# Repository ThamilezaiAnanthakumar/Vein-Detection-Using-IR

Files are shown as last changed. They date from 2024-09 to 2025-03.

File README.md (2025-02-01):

# Vein Detection System  

Enhancing vein detection for healthcare professionals with an efficient and accessible device.  

---  

## 📂 Repository Overview  

This repository contains all the resources and files related to our vein detection system project.  

### **Included Files**  
- **Code Files**: Arduino code for controlling the TFT display.  
- **PCB Files**: Schematic and PCB layout designs detailing hardware connections.  
- **Enclosure Files**: 3D models and designs for the physical enclosure.  
- **Final Report**: Comprehensive documentation including:  
  - Project objectives and design diagrams.  
  - Simulation and testing methodologies.  
  - Results and resource optimization strategies.  
  - Team contributions.  
  - Practical operation instructions.  

---  

## 🛠️ How It Works  

- The system uses an **ESP32-CAM module** to capture real-time images.  
- Images are streamed wirelessly to a browser via Wi-Fi.  
- A **circular LED array** enhances visibility for detecting veins.  
- The built-in **ESP32 camera web server** enables live streaming.  

---

## 💡 Why We Chose the ESP32-CAM  

For this project, we opted for the **ESP32-CAM module** due to second-semester restrictions requiring:  
- Custom PCB design.  
- Soldering for the hardware setup.  

This approach fulfilled the requirements but resulted in lower image quality, a limitation we plan to address in future iterations.  

---

## 🚀 Future Improvements  

To improve the system, we propose:  
1. **Using a Raspberry Pi and NoIR Camera** for better image quality.  
2. **Applying Edge Detection Techniques** to clearly outline veins.  

These enhancements would significantly improve the clarity and usability of the system.  

---

## 🔑 Key Components  

- **ESP32-CAM Module**: Captures and streams real-time images.  
- **Circular LED Array**: Improves vein visibility.  
- **ESP32 Camera Web Server**: Provides a wireless interface for live streaming.  

---

## 🎯 Project Purpose  

This project is designed to assist healthcare professionals by:  
- Making vein detection more efficient.  
- Enhancing the accuracy of procedures like blood draws and cannulation.  

---
👥 Contributors
- [Thamilezai Ananthakumar](https://github.com/ThamilezaiAnanthakumar)- Circuit Design , Documentation,Software Development,Code Integration & Testing
- [Dayananthan](https://github.com/Dayananthan2021)- Circuit Design & PCB Design & Soldering & Testing
- [Imesh Abeysinghe](https://github.com/1234imesh)- Circuit Design & Enclosure Design

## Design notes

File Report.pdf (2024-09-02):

# Vein Detection

Enhancing Precision, Reducing Discomfort in Healthcare

## Project Report

220009H Abeysinghe G. A. I. N. M

220029T Ananthakumar.T

220096T Dayananthan.T

Department of Electronics and Telecommunication Engineering

University of Moratuwa, Sri Lanka

August 22, 2024

## Content

Device Design Report

ABSTRACT

Vein detection technology makes it easier to find veins, which is particularly important for procedures like blood draws and IV insertions. For small children, people with darker skin, and the elderly, locating veins can be challenging due to varying skin types and vein visibility. This system uses infrared light and advanced image processing to clearly display veins on a screen, helping healthcare providers quickly and accurately find veins. This technology not only improves the precision of medical procedures but also reduces discomfort and stress for patients, making it a valuable tool in providing effective and compassionate healthcare.

Device Design Report

### 1. Introduction

In the healthcare sector, accurate and efficient vein detection is crucial. . Traditional vein detection systems can be expensive and often require specialized equipment that is not always accessible in every healthcare setting. Our project addresses these challenges by developing a cost-effective, smart vein detection system that provides a clear and accurate visualization of veins. This device is designed to be accessible via a web-based interface. By offering a budget-friendly solution that combines with ease of use, we aim to improve the efficiency and accuracy of medical procedures while making vein detection more accessible to a broader range of healthcare facilities.

### 2. Background Research

The background research for developing the vein detection system covered several key areas, including hardware components, imaging techniques, and programming languages.The following sections provide an overview of the components and technologies that are integral to the project, ensuring the system is both functional and user-friendly.

ESP WROOM S3 U1 Microcontroller

The ESP WROOM S3 U1 microcontroller is strategically chosen for the vein detection project due to its advanced processing capabilities and substantial memory resources, making it particularly well-suited for image processing tasks. Powered by the ESP32-S3 SoC, this microcontroller features a dual-core Xtensa LX7 processor operating at 240MHz, delivering the high-performance computational power necessary for real-time image analysis. With support for up to 16 MB of PSRAM, the ESP WROOM S3 U1 offers significant memory capacity, enabling efficient handling of complex image data critical for

Device Design Report

Accurate vein detection. Additionally, the integrated Wi-Fi and Bluetooth functionalities facilitate seamless communication of processed data, further solidifying the ESP WROOM S3 U1 as an optimal choice for applications requiring precision and reliability in image-based projects like vein detection compared to other ESP chips

ESP CAM

For the vein detection project, the ESP32-CAM module was selected due to its flexibility and adaptability, particularly in scenarios where a NoIR (No Infrared) camera is essential. While Raspberry Pi cameras with NoIR capability are available, they are not compatible with the ESP32 microcontroller, which is a core component of our project. To address this limitation, we opted to use the ESP32-CAM module and modify it by removing the infrared (IR) filter. This modification allows the camera to capture the infrared wavelengths necessary for effective vein detection.

TFT 1.8’ LCD display

The TFT 1.8” LCD display was chosen for the vein detection project due to its efficient SPI communication, which offers fast data transfer with minimal latency, making it ideal for live streaming applications. The compact size of the display contributes significantly to reducing the overall footprint of the product, aligning with the project’s goal of creating a portable and space-efficient device. Additionally, the cost-effectiveness of the TFT 1.8” LCD display makes it a practical choice, ensuring that the project remains budget-friendly without compromising on performance or quality.

LED Array and IR LED

The design incorporates a circular LED array with IR LEDs strategically placed around the camera, which is positioned at the center. This configuration ensures optimal capture of the reflected infrared light, enhancing the efficacy of image acquisition for vein detection. The IR LEDs operate at a wavelength of 850 nm, which is highly suitable for vein detection due to its ability to penetrate the skin and highlight veins effectively. To ensure the safety and longevity of the LEDs, suitable resistors have been selected to regulate the current, preventing overheating and ensuring consistent performance.

Lithium battery and Charging Module USB Booster

We required a 5V to 8.5V battery to power our PCB, but only 3.7V batteries were available. To meet the voltage requirement, we combined two 3.7V lithium batteries in series. Additionally, since we're using lithium batteries, we included a USB port for recharging the PCB to ensure convenient and reliable power management.

Device Design Report

### 3. Project Description

### 3.1 Circuit Design

In order to develop the vein detection system, we utilized several key schematics to achieve the desired functionality. The primary components used in the circuit include the ESP WROOM S3 U1 microcontroller, a circular IR LED array, potentiometers, resistors, and a camera module. The ESP WROOM S3 U1 managing communication tasks with display. The circular IR LED array, designed with carefully selected resistors and a potentiometer, ensures optimal illumination for vein visualization by providing controlled infrared light around the camera module. The following sections provide an overview of each circuit used in this design,

IR Led Array

The IR LED array schematic was custom-designed based on our specific requirements for the vein detection system. The design process involved manually calculating the resistor values to ensure the safety and longevity of the IR LEDs, preventing overheating and ensuring consistent performance. Additionally, the distance between each LED was carefully calculated to optimize the coverage and intensity of the infrared light, enhancing the efficiency of image capture. By strategically positioning the LEDs in a circular array around the camera, the design maximizes the reflection of infrared light, which is crucial for accurate vein visualization. This custom schematic effectively integrates the IR LED array into the overall system, ensuring high performance and reliability.

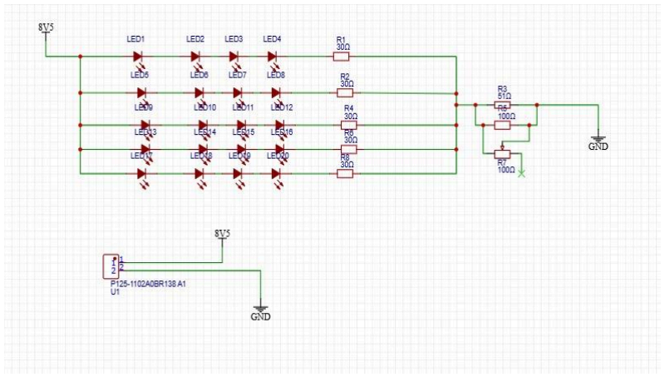
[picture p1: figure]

Device Design Report

ESP WROOM S3 U1

The circuit design began by incorporating the ESP WROOM S3 U1, a powerful and versatile Wi-Fi and Bluetooth-enabled microcontroller, into the system. To ensure stable and efficient performance, we used the ESP WROOM S3 U1 reference circuit provided by Espressif's official documentation as the foundation. Necessary modifications were made to tailor the reference design to the specific needs of our vein detection project, optimizing the circuit for image processing and real-time data communication while maintaining reliability and efficiency.

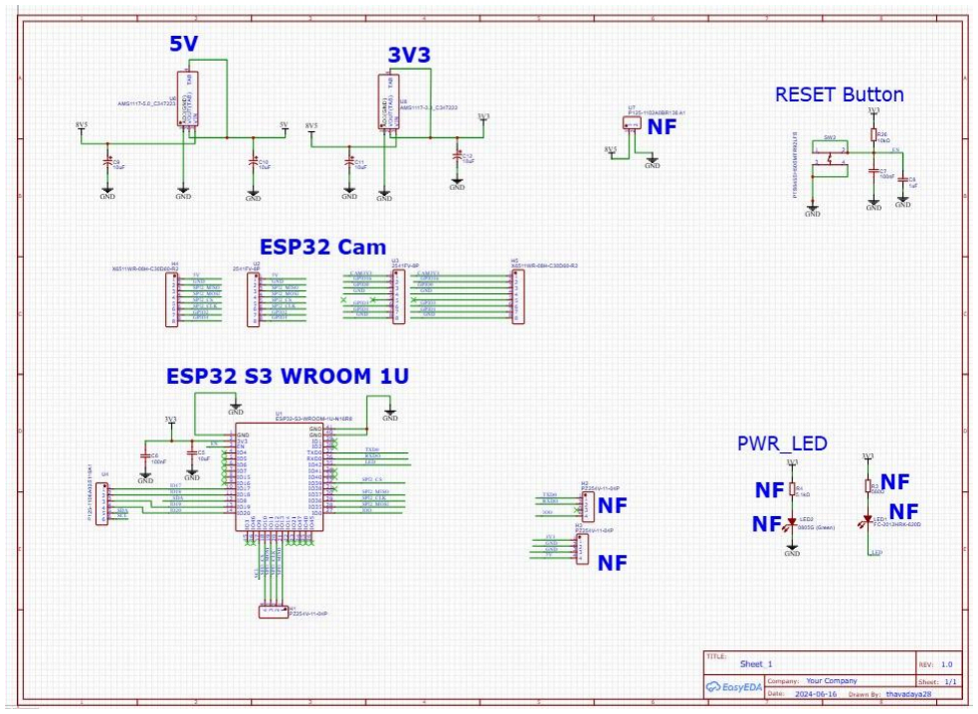
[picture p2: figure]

Device Design Report

### 3.2 PCB Design

The Vein Detection circuit has been designed using Altium Designer, enabling industry-standard PCB (Printed Circuit Board) design. In this section, we will explain various aspects of our PCB layout, including the placement of components, trace width, and clearance for critical nets. We will also discuss specific design rules implemented to ensure that the Vein Detection system operates reliably and without faults.

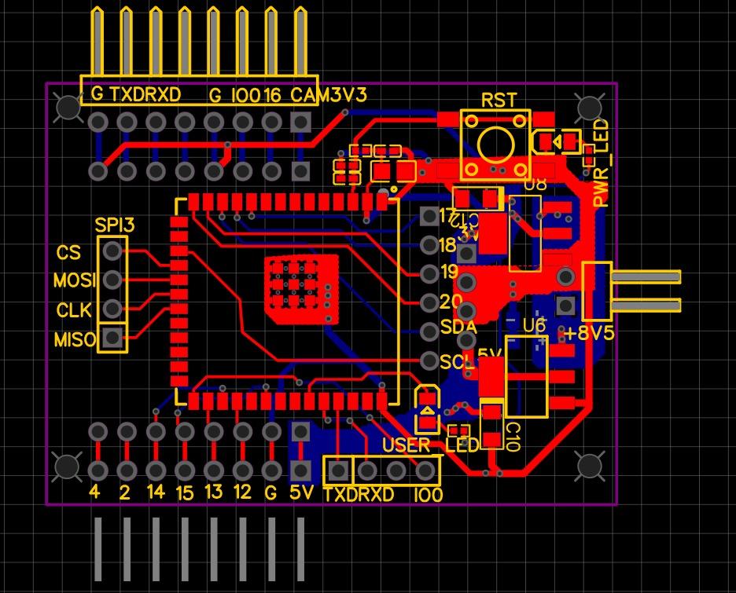
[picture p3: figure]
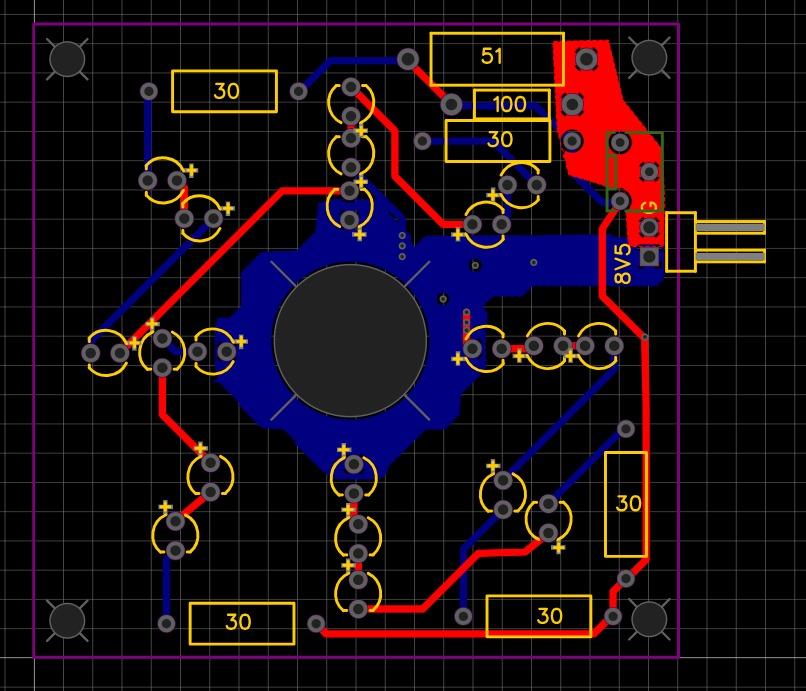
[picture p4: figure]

Device Design Report

Component Placement and 3D Models

In the PCB design process for the Vein Detection system, significant attention was given to the strategic placement of components to optimize performance, minimize noise, facilitate easy soldering, and reduce the overall size of the device. We utilized Altium’s manufacturer part search feature to obtain layouts and 3D models for most components, ensuring that selected parts are readily available in the market. Additionally, the SnapEDA website was used to obtain footprints for some components. The 3D models allowed us to conduct comprehensive mechanical checks, ensuring that there were no interferences with the enclosure or other components, thereby simplifying the assembly process.

Trace Width and Current Considerations

Trace Width and Current Considerations:
In the design of the Vein Detection system, careful attention was given to trace layout, particularly when designing the circular LED PCB where IR LEDs are positioned in close proximity. For the WROOM PCB, we prioritized proper trace sizing to ensure reliable operation and minimize any potential signal interference. Additionally, we incorporated reset buttons and header pins on both sides of the WROOM PCB to facilitate the mounting of the camera module. This strategic placement and trace design were crucial in optimizing the overall functionality and durability of the system.

Clearance and Safety Measures

Electrical safety was a primary concern in the PCB design for the Vein Detection system. To ensure proper operation and safety, we carefully managed clearances, particularly between high-voltage and low-voltage sections. For the camera module, which requires a stable 5V power supply to function correctly, we ensured that the power pins are appropriately designed to deliver the required voltage. This careful design consideration helps prevent operational issues with the camera and enhances the overall safety and reliability of the system.

Device Design Report

Issues with PCB design

Although we designed our PCB properly there is voltage drops less than 5 in each pin.

Future Implementations

In the future, we plan to enhance the PCB design for the Vein Detection system to prevent unwanted interactions, particularly between traces. We will increase the clearances between traces to improve safety and reliability.

Manufacturability and JLCPCB Guidelines:

Throughout the PCB design process, we remained aware of manufacturability requirements of the PCB. We referred to JLCPCB’s manufacturing guidelines to ensure our design complied with their fabrication capabilities and processes. JLCPCB’s .rul file was imported into the "Rules" section of our design software, and necessary changes were made. This proactive approach enabled us to minimize manufacturing errors, reduce production time, and optimize costs

Device Design Report

### 3.3 Enclosure Design

The enclosure design is optimized to ensure even stress distribution. Its curvature reduces the required material by minimizing wall thickness through the creation of hoop stress. Additionally, holes are strategically placed at the center to accommodate the camera.

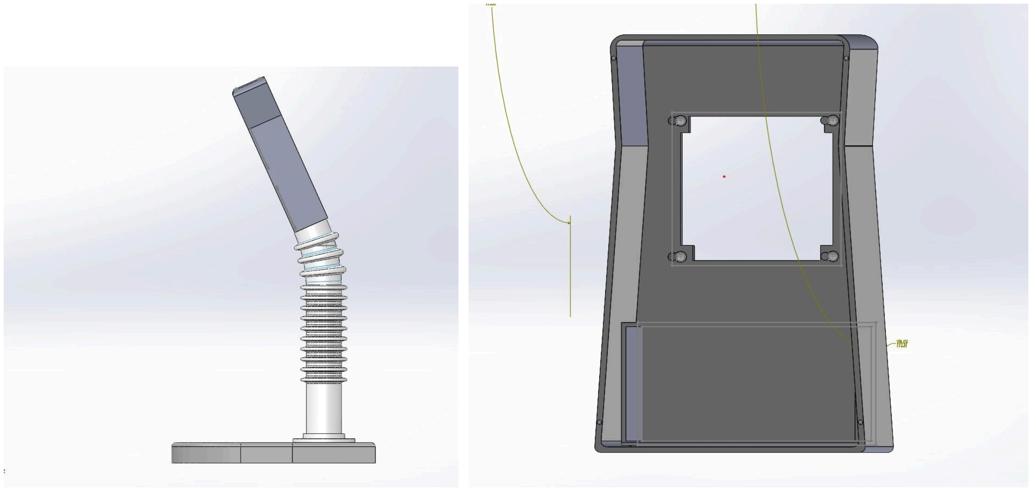
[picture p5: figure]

Technology used : 3D printing
Material used : PLA Bioplastic

The design is a very sleek, compatible and very minimal in size.

Issues with 3D printing :

The poles in the enclosure are breaking due to their small diameter, despite the use of high-quality materials. Additionally, alternative mounting solutions, such as standoffs or brackets, could be explored to reduce reliance on the poles for securing the PCB in the upcoming project. This approach will help to improve the overall durability and structural integrity of the design.

Device Design Report

### 3.4 Microcontroller Programming

We use Wi-Fi libraries and web server libraries to access the camera through a browser over Wi-Fi. For communication between the WROOM module and the display, we utilize SPI communication with the TFT_eSPI library. To simplify the project, we connect only one Wi-Fi network, ensuring a single IP address for both connection and disconnection. Specifically, the WROOM module handles SPI communication and displays the IP address, while the camera module runs the camera server.

Future Implementation

In the future, we plan to use a TFT touch LCD display with an alphanumeric keypad by class defined in Arduino to allow users to input Wi-Fi names and passwords directly on the display. This will enable the system to connect to various Wi-Fi networks, each with its own unique IP address. The WROOM and camera modules will then communicate to share Wi-Fi credentials and IP addresses, facilitating seamless connectivity and operation.

### 4. Non-technical issues

We faced unexpected costs because we had to buy components from China, adding $70 in shipping fees to our budget. Additionally, the TFT display was out of stock in Sri Lanka, which also required international shipping. As this is our first complete project, we weren’t prepared for these issues. For future projects, we will research suppliers more thoroughly, budget for unforeseen costs, seek local alternatives, plan logistics more carefully, and discuss cost-sharing arrangements with partners or clients to prevent similar problems.

### 5. Our progress and Limitations

### 1. Initial Idea: Live Stream Image Processing with OpenCV

- We aimed to capture live stream images using the ESP32-CAM and send them via Wi-Fi to a system running OpenCV for advanced image processing tasks, such as edge detection and noise removal.

Device Design Report

- The processed image was to be sent back to the WROOM chip, which, equipped with PSRAM, would then buffer and display the image on a TFT display through SPI communication.
- However, this approach encountered network termination errors with the OpenCV code, leading us to abandon this plan after unsuccessful implementation attempts.

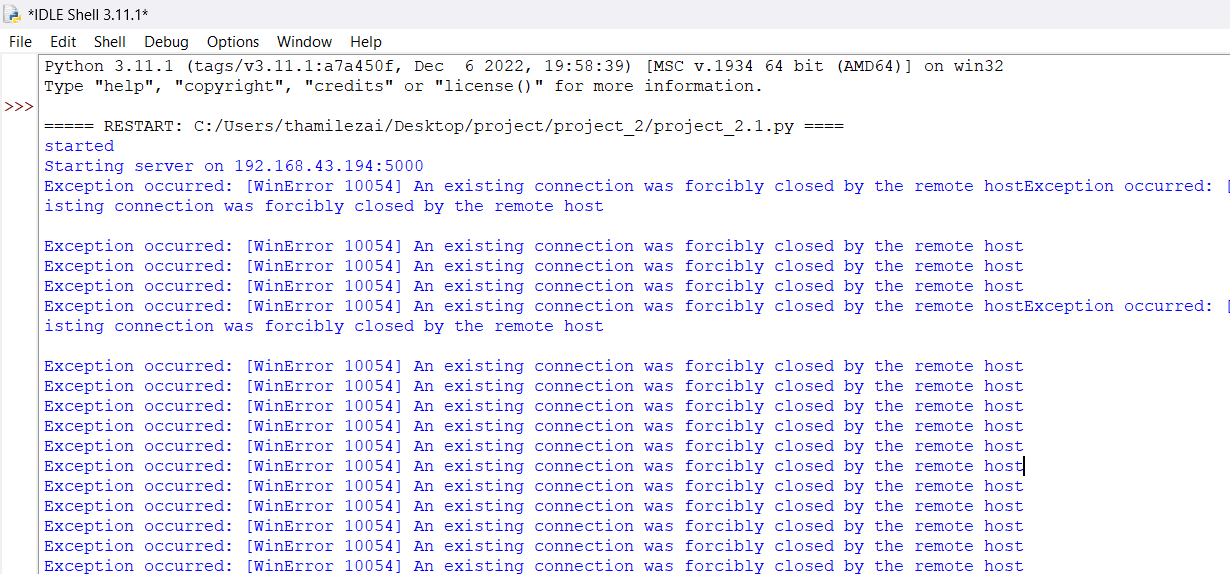
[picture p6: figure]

### 2. Alternative Approach: Simplified Image Processing with Arduino IDE

- We considered removing the OpenCV component and opted to capture images with the ESP32-CAM, apply basic noise removal using Arduino IDE, and then send the processed image to the TFT display via SPI communication.
- Unfortunately, the TFT display faced hardware limitations that prevented it from effectively displaying live-streamed images; it could handle text and graphics but struggled with image data, resulting in high noise and stuck frames.

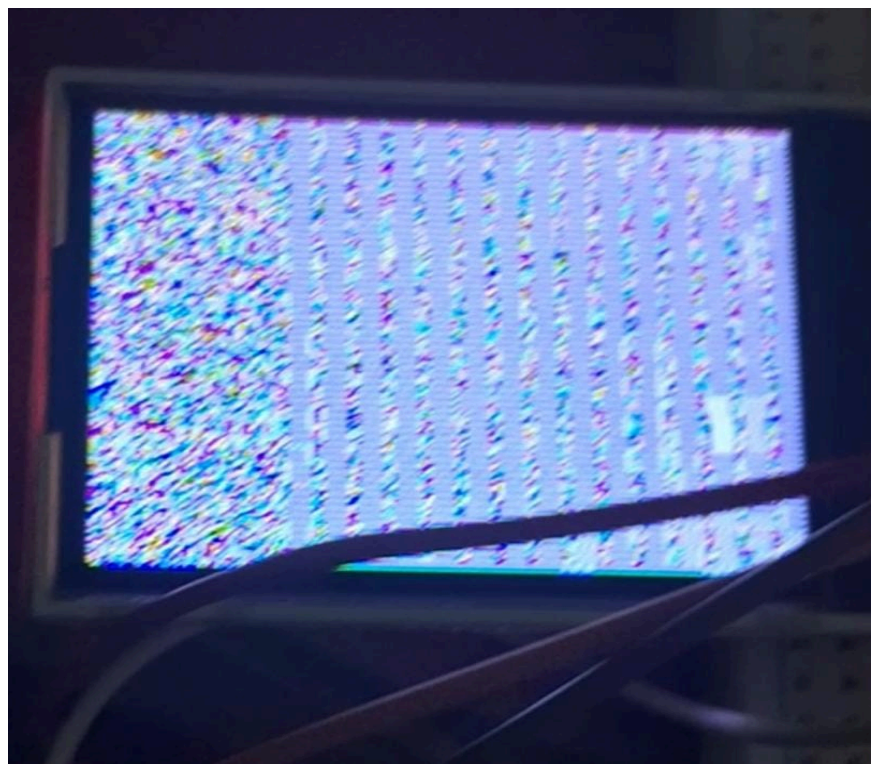
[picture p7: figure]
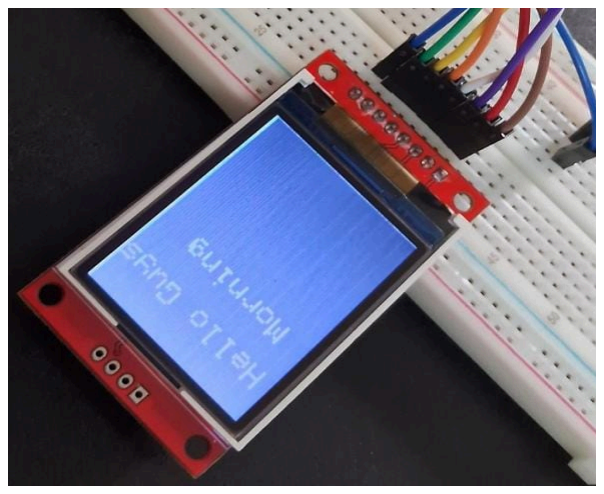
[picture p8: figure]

Device Design Report

### 3. Final Solution: Web Browser Display via Camera Server

- Given the issues with the TFT display, we shifted to displaying the captured image in a web browser using the camera server feature of the ESP32-CAM, utilizing web server and Wi-Fi libraries.
- By typing the IP address into a browser, users can view the image, and the WROOM chip displays this IP address on the TFT screen, which remains constant for a single Wi-Fi Connection.

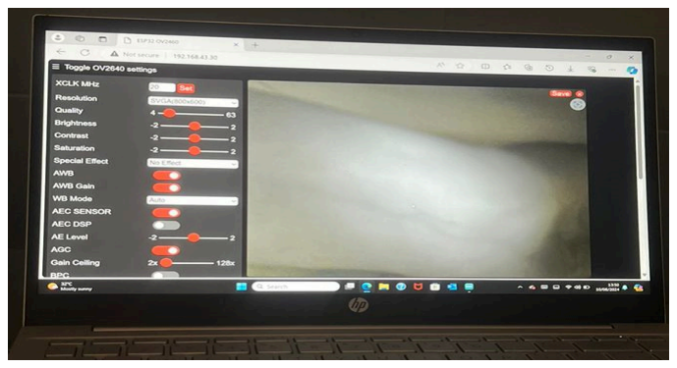
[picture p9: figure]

Camera Web Server Vein

### 4. Future Considerations: Mobile Accessibility

- After discussions with medical professionals, we learned that mobile accessibility is preferred for future projects. This feedback has led us to focus on solutions that are more mobile-friendly, aligning with user preferences and improving overall usability.
Each step reflects a thoughtful progression, responding to technical challenges and user feedback, leading to a more robust and user-centric solution.

Device Design Report

6.Task Allocation

Name | Task Allocation
Abeysinghe G. A. I. N. M | Product Enclosure Design with SolidWorks. Testing and Troubleshooting
Ananthakumar.T | Program Development. Testing and Troubleshooting
Dayananthan.T | PCB Designing using Altium and Product Soldering and Assembling the product. Testing and Troubleshooting

### 7. Conclusion and Future Work

Our project initially focused on developing a vein detection system, overcoming challenges related to image capture and processing. Despite technical and hardware limitations, we made significant progress in integrating components like the ESP32-CAM and TFT display. However, we faced issues with live image streaming and processing due to hardware constraints and network termination errors, which led us to pivot our approach multiple times.
Looking ahead, our future plan is to implement a 2.8" TFT touch display with an alphanumeric keypad, enabling users to input their network name and password directly on the device. This will allow for dynamic Wi-Fi connectivity, with communication between the WROOM and CAM modules to update and display variable IP addresses on the TFT screen. We aim to achieve this by defining classes for numeric and alphabetic input in Arduino IDE, enhancing the programming capabilities and functionality of the system.
Currently, we are facing some hardware limitations and time constraints, which have delayed the full implementation of these features. We plan to address these issues and complete the coding in the future, ultimately enabling the device to be more versatile and accessible via Wi-Fi for various users.

Device Design Report

### 7. Appendices

ESP- S3-WROOM-U1 : esp32-s3-wroom-1_wroom-1u_datasheet_en.pdf (espressif.com) (https://www.espressif.com/sites/default/files/documentation/esp32-s3-wroom-1_wroom-1u_datasheet_en.pdf)

ESP CAM : ESP32-CAM Camera Module Pinout, Datasheet, Features and Specs (components101.com) (https://components101.com/modules/esp32-cam-camera-module)

TFT 1.8’ display : 1.8" TFT Display Breakout and Shield Datasheet by Adafruit Industries
LLC | Digi-Key Electronics (digikey.com) (https://www.digikey.com/htmldatasheets/production/1942395/0/0/1/1-8-tft-display-breakout-and-shield.html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)

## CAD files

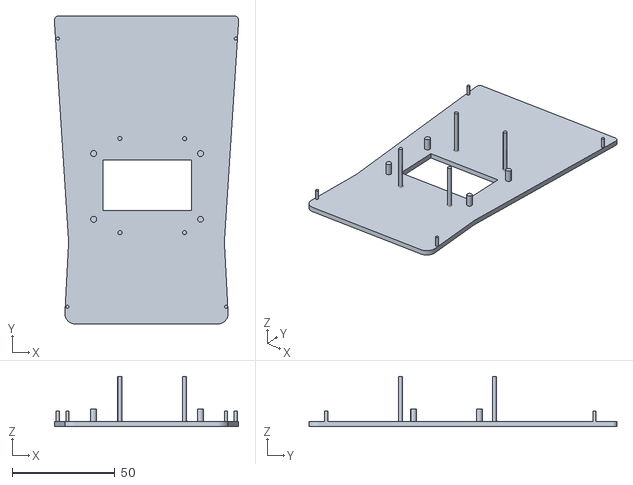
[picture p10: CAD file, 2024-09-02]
Enclosure/Main_Header.STL
89.7 x 149.9 x 24.5

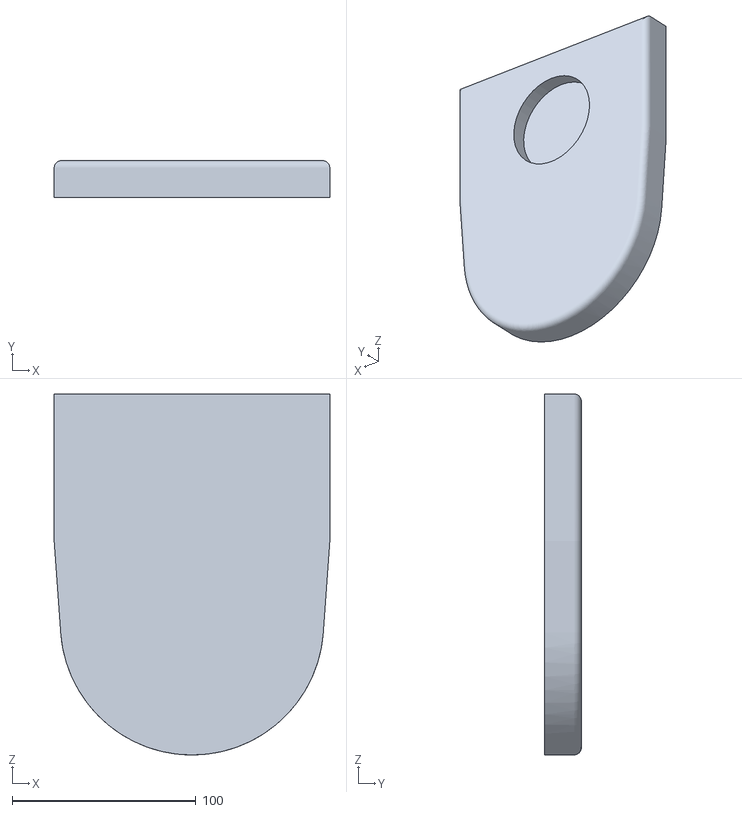
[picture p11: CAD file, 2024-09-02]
Enclosure/base.STL
150.0 x 20.0 x 196.4

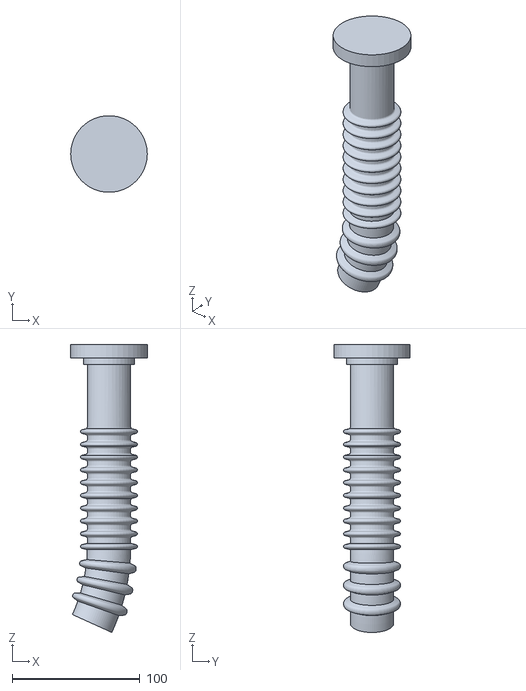
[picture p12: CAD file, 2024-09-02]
Enclosure/Bendable Neck.STL
60.0 x 59.8 x 225.5

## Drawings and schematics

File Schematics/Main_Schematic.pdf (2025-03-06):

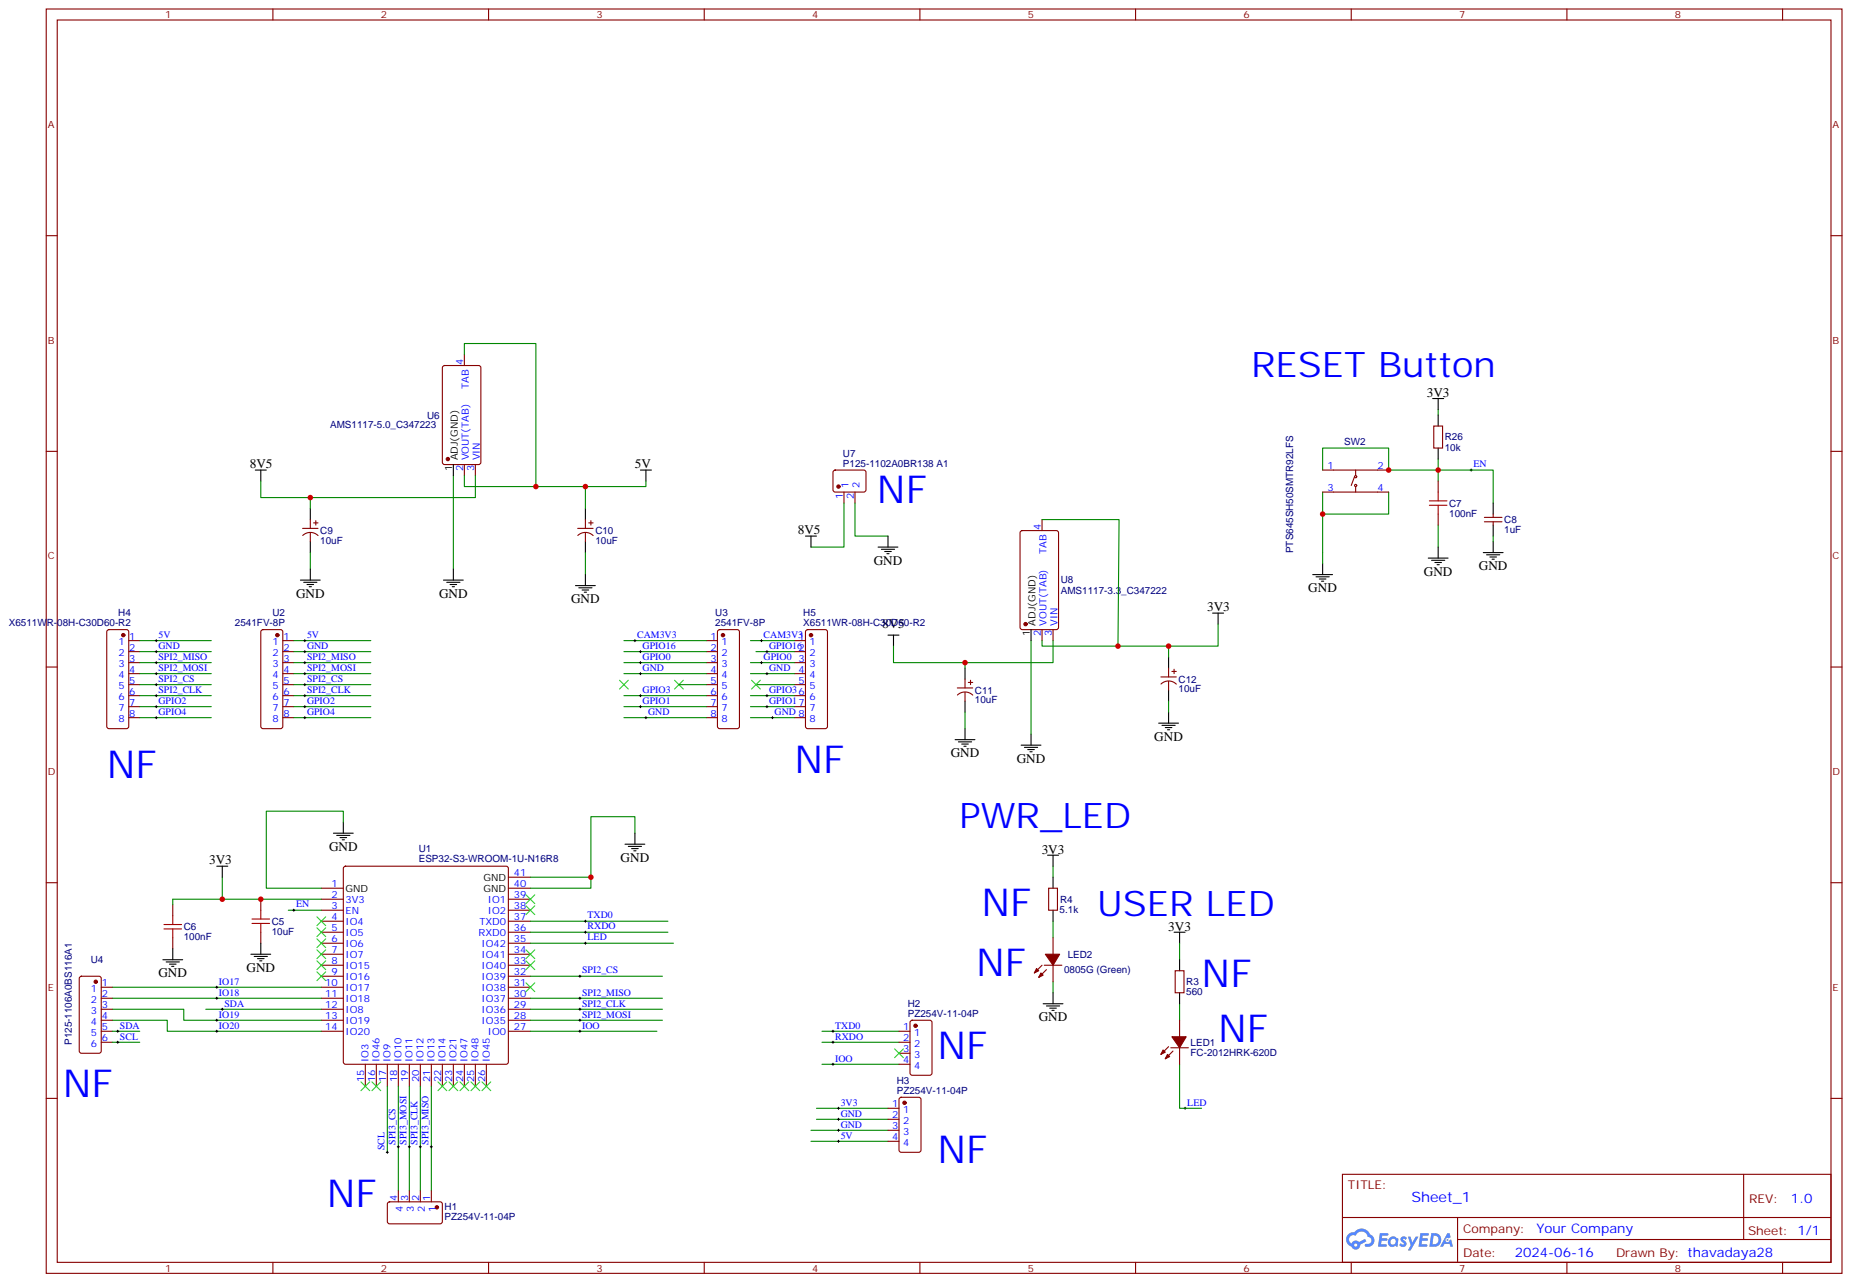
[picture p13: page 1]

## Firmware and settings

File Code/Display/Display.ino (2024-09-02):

#include <Adafruit_GFX.h>    // Core graphics library
#include <Adafruit_ST7735.h> // Hardware-specific library for ST7735
#include <SPI.h>

// Pin definitions for ESP32
#define TFT_CS      10    
#define TFT_RST     19   
#define TFT_DC      17   
#define TFT_MOSI    13  
#define TFT_SCLK    12   

// Create Adafruit ST7735 instance
Adafruit_ST7735 tft = Adafruit_ST7735(TFT_CS, TFT_DC, TFT_MOSI, TFT_SCLK, TFT_RST);

void setup(void) {
  Serial.begin(115200);

  // Initialize the display
  tft.initR(INITR_BLACKTAB);  // Init ST7735S chip, black tab

  // Set the background color to black
  tft.fillScreen(ST77XX_BLACK);

  // Display "Initializing....."
  tft.setTextColor(ST77XX_WHITE);
  tft.setTextSize(1);
  tft.setCursor(10, 50);
  tft.println("Initializing.....");
  
  delay(5000);

  // Clear the screen and display IP information
  tft.fillScreen(ST77XX_BLACK);
  tft.setTextColor(ST77XX_WHITE);
  tft.setTextSize(1);

  // Set cursor for each line
  tft.setCursor(10, 30);  // Set cursor for "IP Address"
  tft.print("IP Address:");
  
  tft.setCursor(10, 50);  // Set cursor for the actual IP address
  tft.println("192.168.10.30");

  tft.setCursor(10, 70);  // Set cursor for "Browse it"
  tft.println("Browse it");
}

void loop() {
  // The loop function remains empty since we only want to display the text once.
}
